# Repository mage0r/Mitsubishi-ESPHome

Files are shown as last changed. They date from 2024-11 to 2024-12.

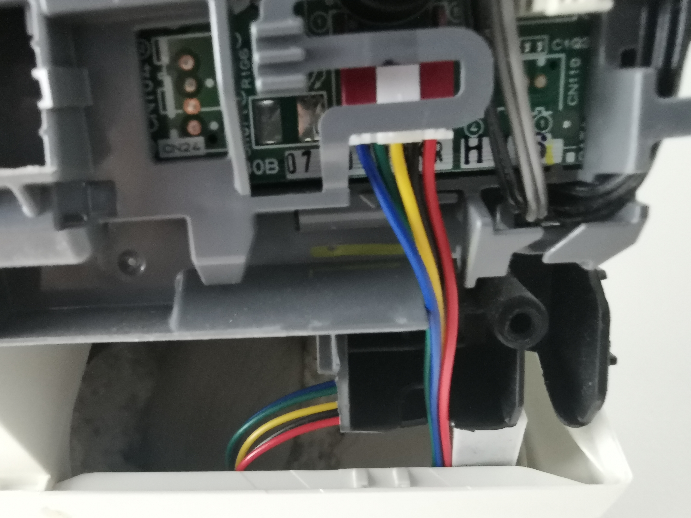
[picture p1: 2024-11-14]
Photos/2024-11-03 16.38.21.jpg

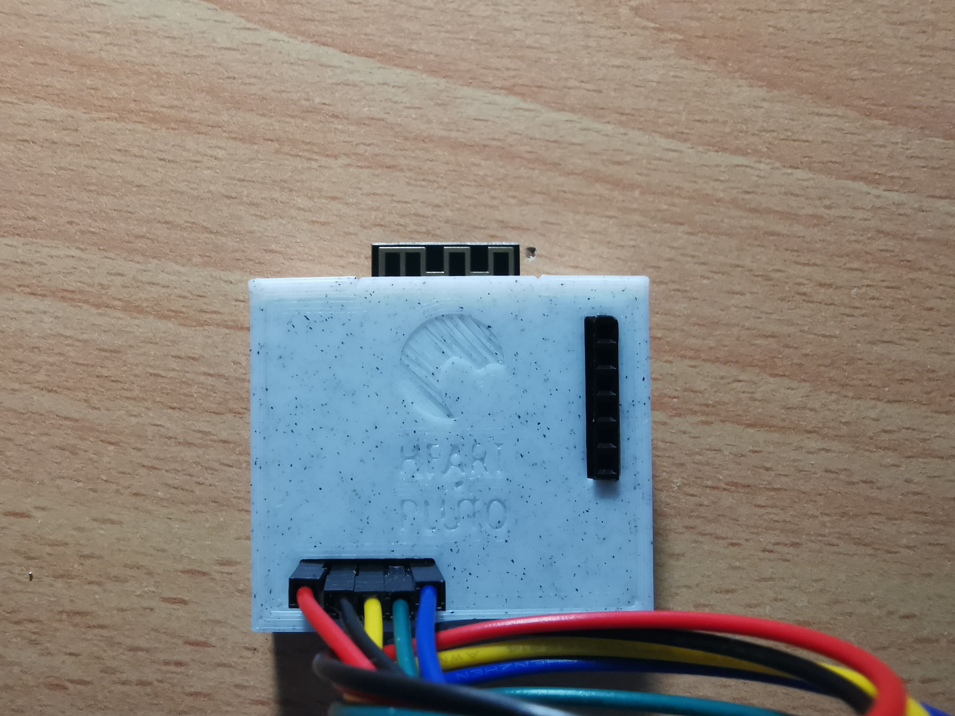
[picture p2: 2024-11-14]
Photos/2024-11-03 16.27.00.jpg

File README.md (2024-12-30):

# Mitsubishi ESPHome
 Controller board for Mitsubishi ESPHome 

Having 5 of these units and recently going way to deep on the whole Solar + Home Assistant I looked for a simple circuit I could just plug in and move on with my life.

I couldn't find one.  Everything was jamming some pins on a D1 mini or overkilling it with a Raspberry Pi.

So I looked really, really closely at:
https://chrdavis.github.io/hacking-a-mitsubishi-heat-pump-Part-1/
https://nicegear.nz/blog/hacking-a-mitsubishi-heat-pump-air-conditioner/

And used them to design my own.

To do the inital program for this you will need a Superhouse.tv ESPFlasher (https://www.superhouse.tv/product/espflasher-esp8266-esp32-usb-serial-flasher/)

I've included a config example for ESPHome.

To integrate this with Home Assistant.
https://github.com/echavet/MitsubishiCN105ESPHome

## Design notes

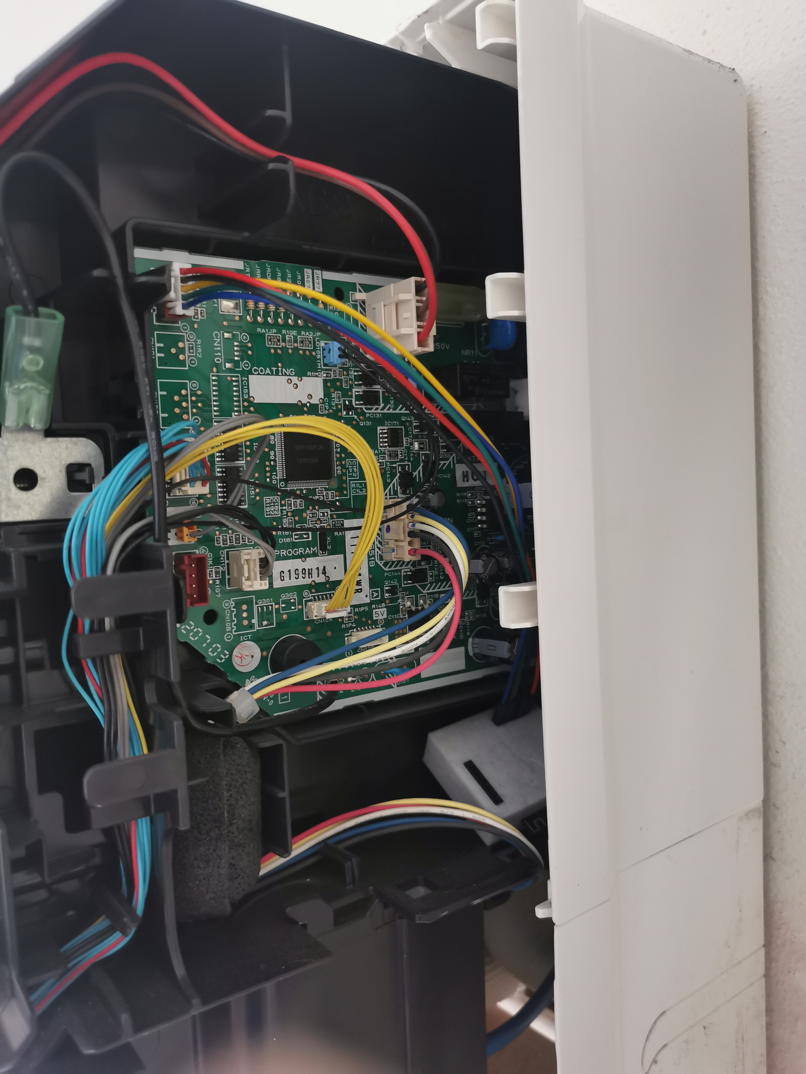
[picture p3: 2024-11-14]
Photos/2024-11-04 15.47.32.jpg

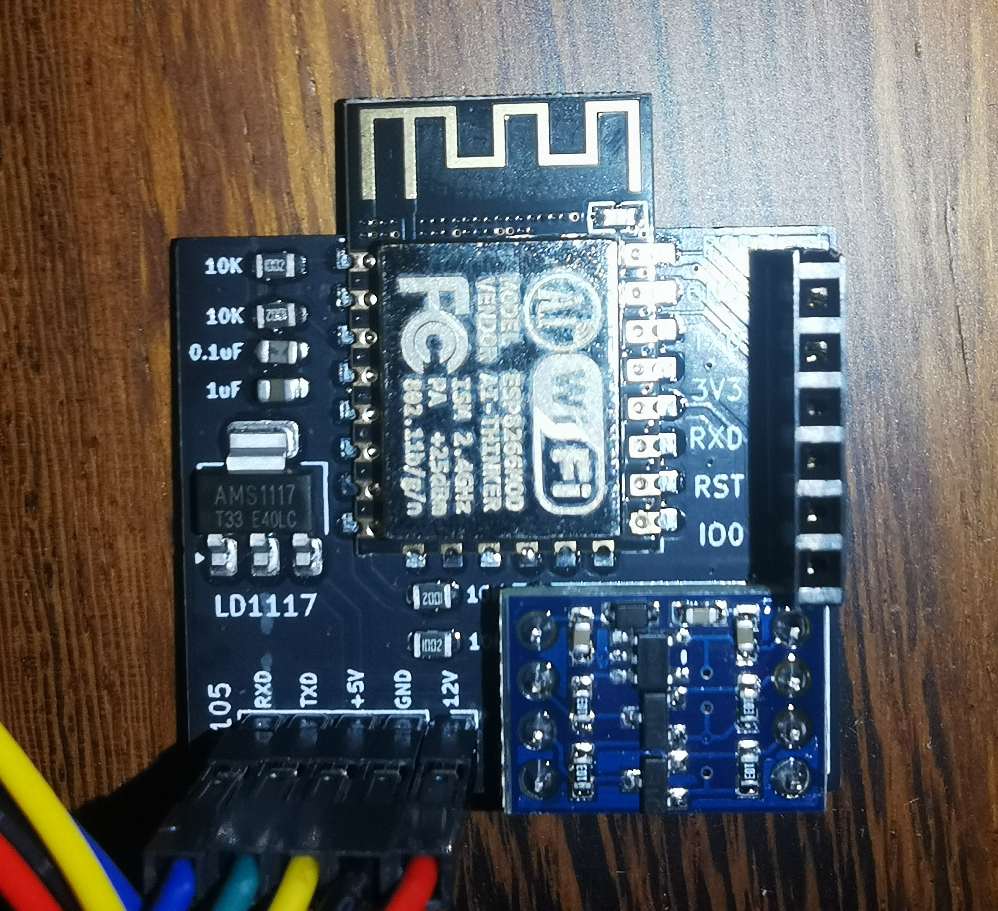
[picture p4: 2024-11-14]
Photos/2024-11-01 20.58.46.jpg

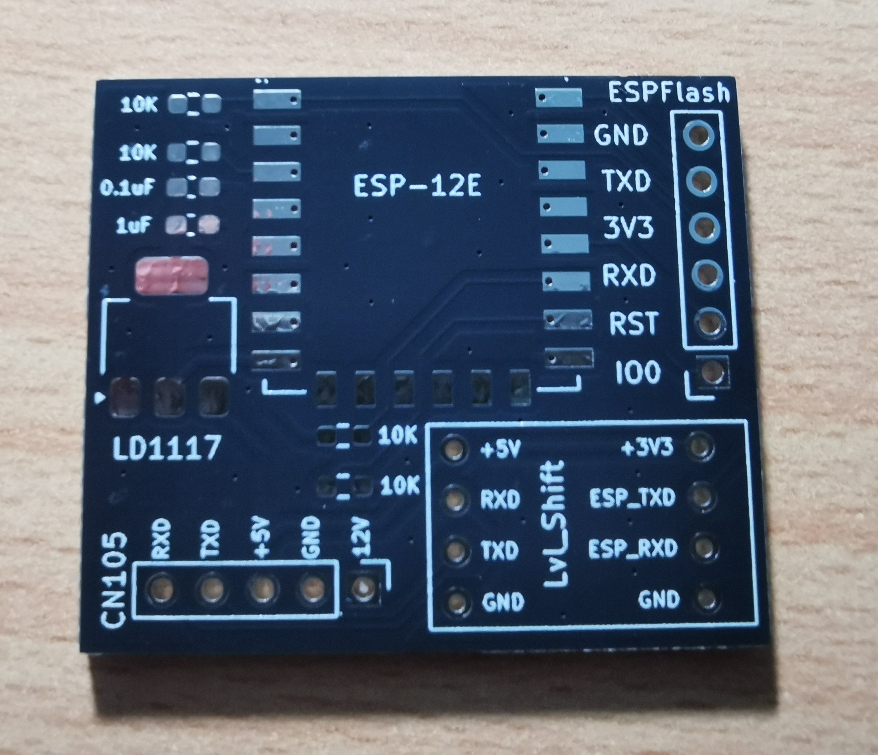
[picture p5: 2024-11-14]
Photos/2024-11-03 16.29.41.jpg

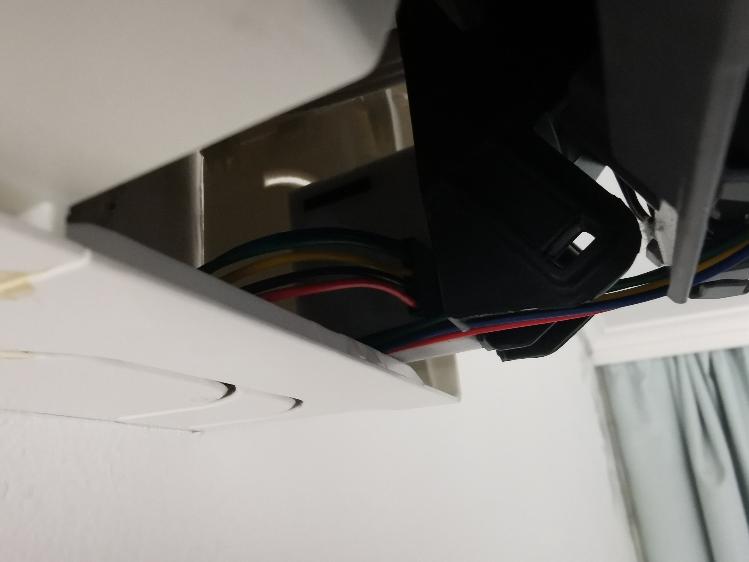
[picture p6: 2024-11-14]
Photos/2024-11-03 16.38.46.jpg

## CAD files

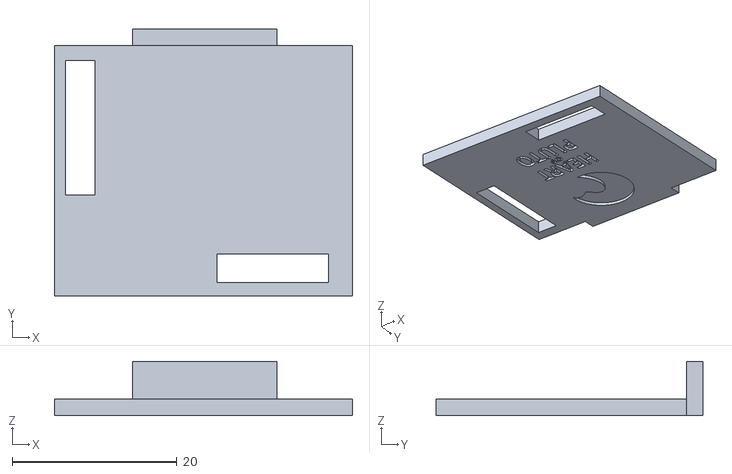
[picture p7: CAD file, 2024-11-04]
case.1.0.top.stl
36.2 x 32.4 x 6.60

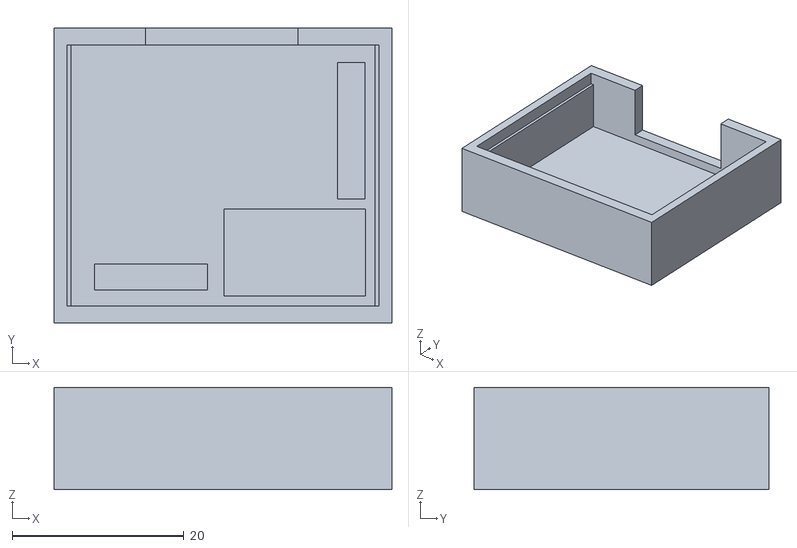
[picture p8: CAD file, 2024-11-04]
case.1.0.bottom.stl
39.4 x 34.4 x 11.9

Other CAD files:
mitsubishi-aircon-F_Silkscreen.dxf

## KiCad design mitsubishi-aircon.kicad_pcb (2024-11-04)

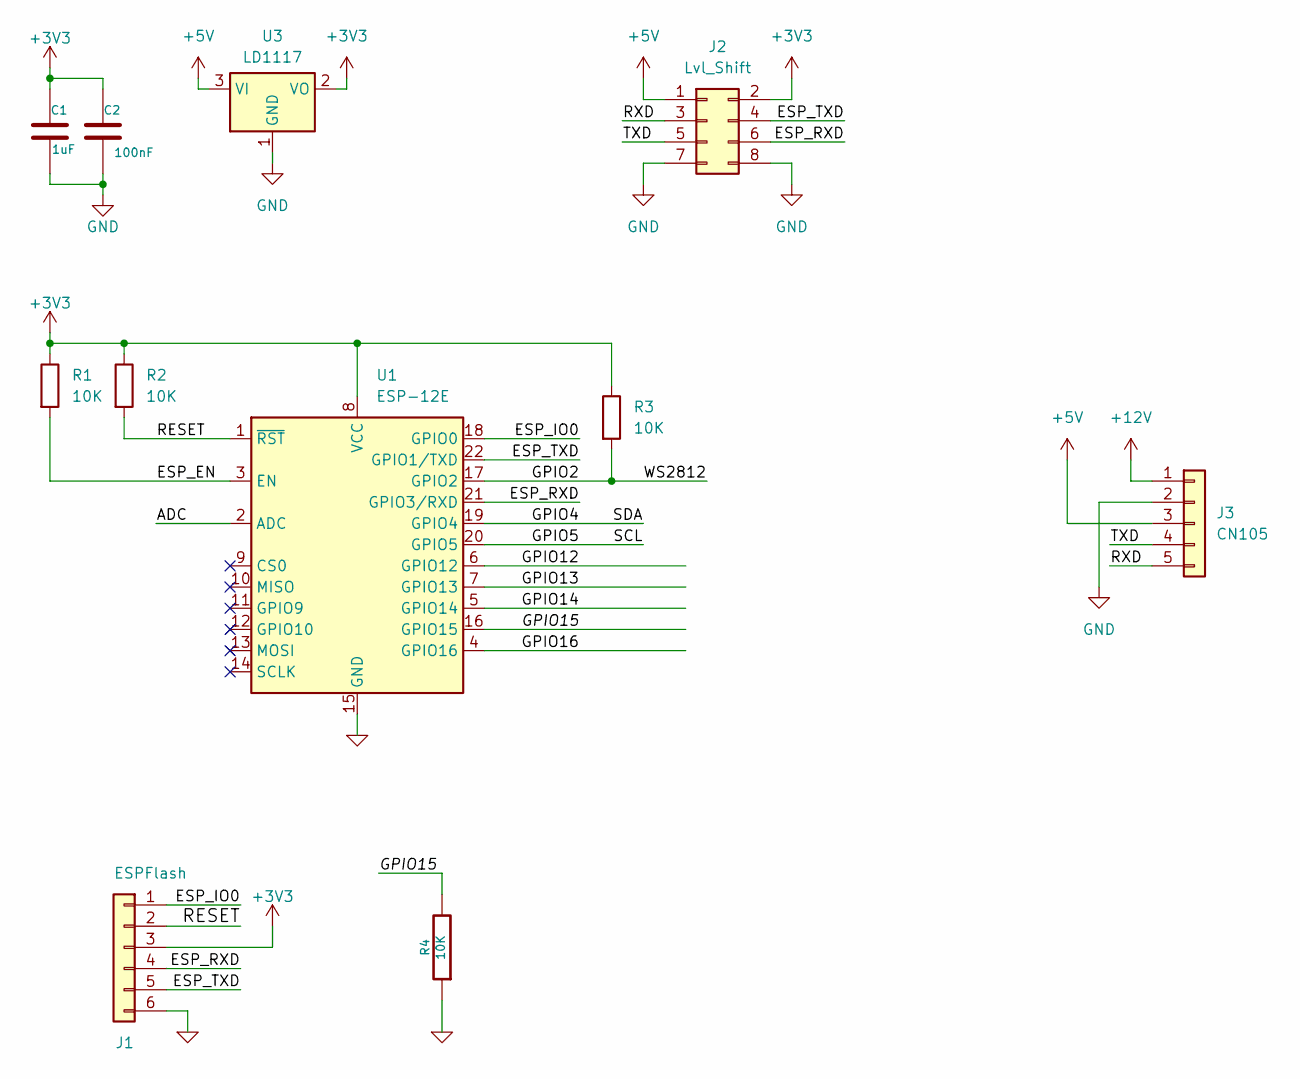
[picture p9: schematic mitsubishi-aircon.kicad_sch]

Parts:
C1: 1uF; C_0603_1608Metric_Pad1.08x0.95mm_HandSolder
C2: 100nF; C_0603_1608Metric_Pad1.08x0.95mm_HandSolder
J1: ESPFlash
J2: Lvl_Shift; lvl_shift
J3: CN105; PinHeader_1x05_P2.54mm_Vertical
R1, R2, R3, R4: 10K; R_0603_1608Metric_Pad0.98x0.95mm_HandSolder
U1: ESP-12E
U3: LD1117; SOT-223-3_TabPin2

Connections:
+3V3: C1.1, C2.1, J1.3, J2.2, R1.1, R2.1, R3.1, U1.8 (VCC), U3.2 (VO)
+5V: J2.1, J3.3, U3.3 (VI)
+12V: J3.1
/ADC: U1.2 (ADC)
/ESP_EN: R1.2, U1.3 (EN)
/ESP_IO0: J1.1, U1.18 (GPIO0)
/ESP_RXD: J1.4, J2.6, U1.21 (GPIO3/RXD)
/ESP_TXD: J1.5, J2.4, U1.22 (GPIO1/TXD)
/GPIO2: R3.2, U1.17 (GPIO2)
/GPIO4: U1.19 (GPIO4)
/GPIO5: U1.20 (GPIO5)
/GPIO12: U1.6 (GPIO12)
/GPIO13: U1.7 (GPIO13)
/GPIO14: U1.5 (GPIO14)
/GPIO15: R4.2, U1.16 (GPIO15)
/GPIO16: U1.4 (GPIO16)
/RESET: J1.2, R2.2, U1.1 (~RST)
/RXD: J2.3, J3.5
/TXD: J2.5, J3.4
GND: C1.2, C2.2, J1.6, J2.7, J2.8, J3.2, R4.1, U1.15 (GND), U3.1 (GND)

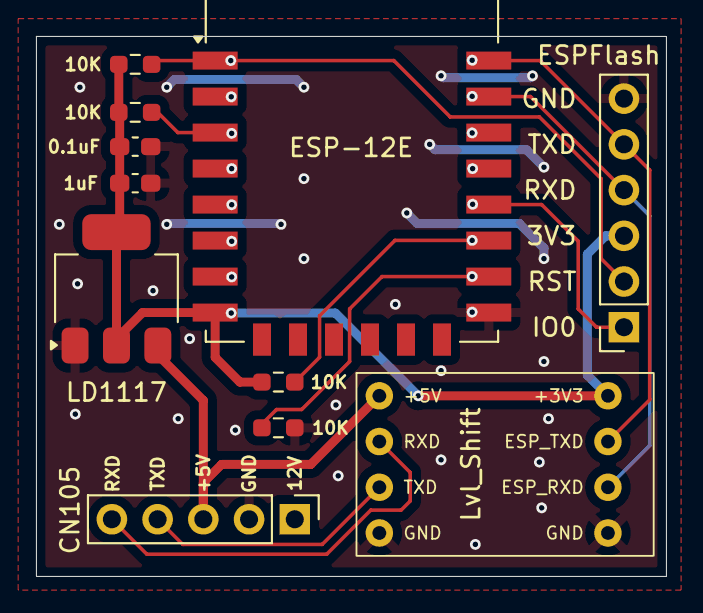
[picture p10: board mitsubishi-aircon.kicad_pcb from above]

Board: 2 copper layers, 35.0 x 30.0 mm, 11 parts (0 on the bottom side), 12 nets.

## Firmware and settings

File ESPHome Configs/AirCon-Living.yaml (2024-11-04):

substitutions:
  name: aircon-living
  friendly_name: AirCon-Living

esphome:
  name: ${name}
  friendly_name: ${friendly_name}

esp8266:
  board: esp01_1m

# Enable Home Assistant API
api:
  encryption:
    key: "PUT YOUR OWN KEY"
  services:
  - service: set_remote_temperature
    variables:
      temperature: float
    then:
# Select between the C version and the F version
# Uncomment just ONE of the below lines. The top receives the temperature value in C,
# the bottom receives the value in F, converting to C here.
      - lambda: 'id(hp).set_remote_temperature(temperature);'
#        - lambda: 'id(hp).set_remote_temperature((temperature - 32.0) * (5.0 / 9.0));'
  - service: use_internal_temperature
    then:
      - lambda: 'id(hp).set_remote_temperature(0);'

# Sync time with Home Assistant.
time:
  - platform: homeassistant
    id: homeassistant_time

# Sensors with general information.
sensor:
  # Uptime sensor.
  - platform: uptime
    name: ${name} Uptime

  # WiFi Signal sensor.
  - platform: wifi_signal
    name: ${name} WiFi Signal
    update_interval: 120s

# Create a button to restart the unit from HomeAssistant. Rarely needed, but can be handy.
button:
  - platform: restart
    name: "Restart ${friendly_name}"

# switch to turn off the annoying LED
switch:
  - platform: gpio
    pin: GPIO2
    name: onboardled
    inverted: True
    id: annoyingled
    restore_mode: ALWAYS_OFF

ota:
  - platform: esphome
    password: "PASSWORD"

wifi:
  ssid: !secret wifi_ssid
  password: !secret wifi_password

  # Enable fallback hotspot (captive portal) in case wifi connection fails
  ap:
    ssid: "Aircon-Living Fallback Hotspot"
    password: "PASSWORD"

captive_portal:

uart:
  id: HP_UART
  baud_rate: 2400
  tx_pin: 1
  rx_pin: 3

# External component reference
external_components:
  - source: github://echavet/MitsubishiCN105ESPHome

# Climate entity configuration
climate:
  - platform: cn105
    id: hp
    name: "Living Room AirCon"
    update_interval: 4s        # update interval can be ajusted after a first run and logs monitoring* 
    icon: mdi:heat-pump
    visual:
      min_temperature: 15
      max_temperature: 31
      temperature_step:
        target_temperature: 1
        current_temperature: 0.1
    compressor_frequency_sensor:
      name: ${name} Compressor Frequency
    outside_air_temperature_sensor:
      name: ${name} Outside Air Temperature
    vertical_vane_select:
      name: ${name} Vertical Vane
    horizontal_vane_select:
      name: ${name} Horizontal Vane
    remote_temperature_timeout: 30min
    debounce_delay : 500ms 

# Default logging level
logger:
  hardware_uart: UART1 # This line can be removed for ESP32 devices
  level: INFO
  logs:
    EVT_SETS : INFO
    WIFI : INFO
    MQTT : INFO
    WRITE_SETTINGS : INFO
    SETTINGS : INFO
    STATUS : INFO
    CN105Climate: WARN
    CN105: INFO
    climate: WARN
    sensor: WARN
    chkSum : INFO
    WRITE : WARN
    READ : WARN
    Header: INFO
    Decoder : INFO
    CONTROL_WANTED_SETTINGS: INFO
